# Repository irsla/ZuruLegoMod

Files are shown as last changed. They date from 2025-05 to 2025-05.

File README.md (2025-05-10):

# ZuruLegoMod
Hardware Mod for the Zuru Max Retro Computer Lego

This project was created for a friend (@CabriDIY) , it hasn't been curated and will most certainly not get any update.













## Building the firmware

The source code should build with any arm-none-eabi- GCC compilers.

```console
$ make
[...]
arm-none-eabi-size build/firmware_LegoZuru.elf
   text	   data	    bss	    dec	    hex	filename
 737740	    200	 191496	 929436	  e2e9c	build/firmware_LegoZuru.elf
arm-none-eabi-objcopy -O ihex build/firmware_LegoZuru.elf build/firmware_LegoZuru.hex
arm-none-eabi-objcopy -O binary -S build/firmware_LegoZuru.elf build/firmware_LegoZuru.bin
```

## Hardware

**The hardware was generated on KiCad**
  - schematics (pdf)
  - gerbers
  - BOMs
  - positions
  - 3D stl
  - Tutorial - photo only (PDF)

Project was manufactured and assembled by JLCPCB
 
**Not Included in the documentation:**
 - OLED Display: NHD-1.8-160128B, datasheet in folder Hardware
 - FPV ribbon: 10pin 0.5mm pitch type A (careful **not** to use a type B)
 - Power: any 5V, we used a 5V only usb cable

## Some photos

### 211 lego pieces:



### very first try of a GIF (I think the color was not correctly parsed)



### Oh No I have a dead pixel



### first main board was incorrect (I had to bodge)

signal-2025-04-14-19-46-56-328

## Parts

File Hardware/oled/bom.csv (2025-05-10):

Designator | Footprint | Quantity | Value | LCSC Part #
C17 | C_0402 | 1 | 4.7uF 50V
C18 | C_0402 | 1 | 4.7uF
C19 | C_0402 | 1 | 0.1uF
C20, C21, C22 | C_0402 | 3 | 1uF
D3, D4 | RB500VM-40TE-17 | 2 | RB500VM
J1 | HC-FPC-05-LT-10RLTAG | 1 | HC-FPC-05-LT-10RLTAG
J2 | F-FPC0N34P-D311 | 1 | ~
R1 | R_0402 | 1 | 49.9
R3 | R_0402 | 1 | 1.2M

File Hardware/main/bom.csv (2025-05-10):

Designator | Footprint | Quantity | Value | LCSC Part #
C1, C2 | C_0402 | 2 | 15pF
C10, C27 | C_0402 | 2 | 4.7uF
C11, C12, C16, C24, C28, C5, C6, C7, C8, C9 | C_0402 | 10 | 100nF
C13, C14 | C_0402 | 2 | 2.2uF
C15 | C_0402 | 1 | 1uF
C23, C25 | C_0805 | 2 | 22uF
C26 | C_0402 | 1 | 10uF
C3, C4 | C_0402 | 2 | 5.6pF
D1 | TJ-S4008SW4TGLCCW-A5 | 1 | ~
D2 | RB500VM-40TE-17 | 1 | RB500VM
J4 | J_SWD | 1 | ~
J5 | Header_1x02_2.54_TH_labels | 1 | ~
J6 | HC-FPC-05-LT-10RLTAG | 1 | HC-FPC-05-LT-10RLTAG
L1 | L_0603 | 1 | 4.7uH
R10, R11, R12, R7, R8, R9 | R_0402 | 6 | 47K
R13 | R_0402 | 1 | 200
R2 | R_0402 | 1 | 100K
R4 | R_0402 | 1 | 220K 1%
R5 | R_0402 | 1 | 18K 1%
R6 | R_0402 | 1 | 270K 1%
U1 | STM32H563VIT6 | 1 | ~
U2 | EA2208 | 1 | EA2208T6R
U3 | TPS7B6933 | 1 | TPS7B6933DBVR
U4 | Molex_uSD_Card_503398-1892 | 1 | MOLEX-SDCARD-503398-1892
Y2 | NX2016SA-25MHZ-STD-CZS-2 | 1 | NX2016SA-25MHZ-STD-CZS-2
Y3 | ABS25-32.768KHz | 1 | 32.768KHZ

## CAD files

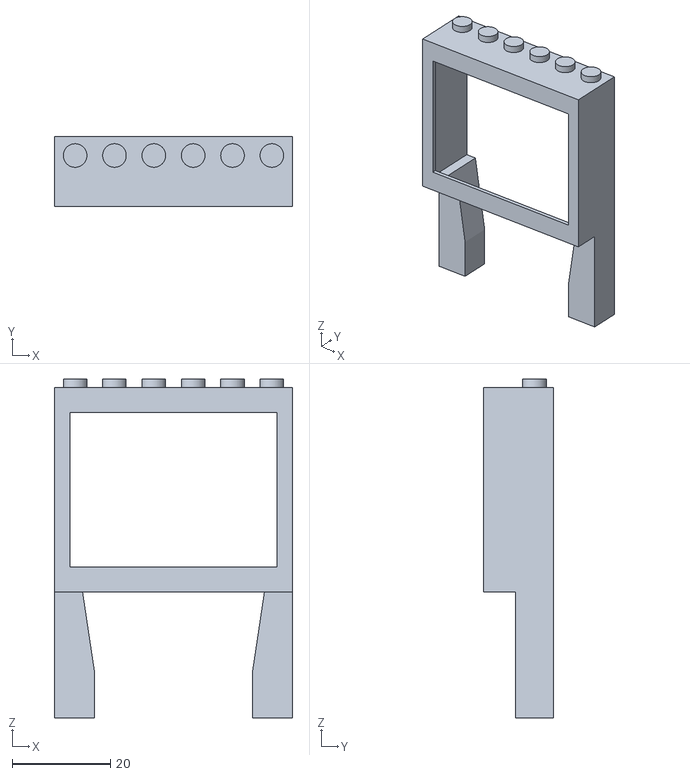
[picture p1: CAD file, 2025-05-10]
Hardware/DisplayHolder/display_case.stl
48.4 x 14.3 x 68.9

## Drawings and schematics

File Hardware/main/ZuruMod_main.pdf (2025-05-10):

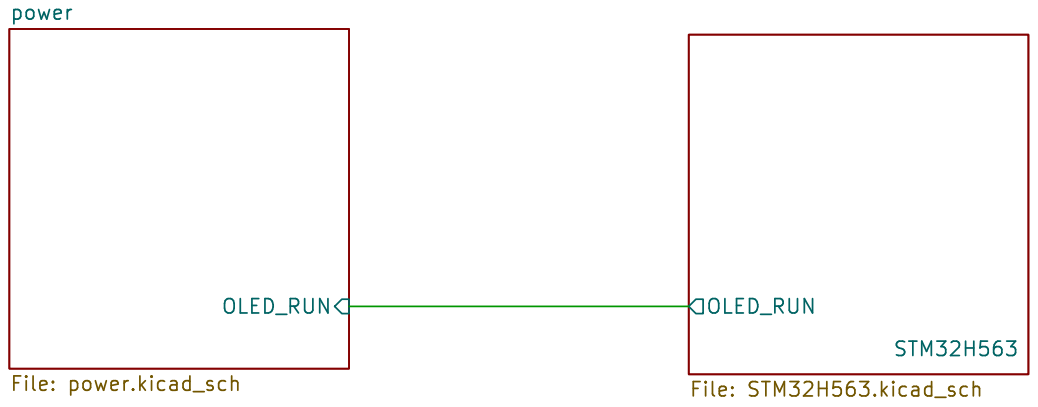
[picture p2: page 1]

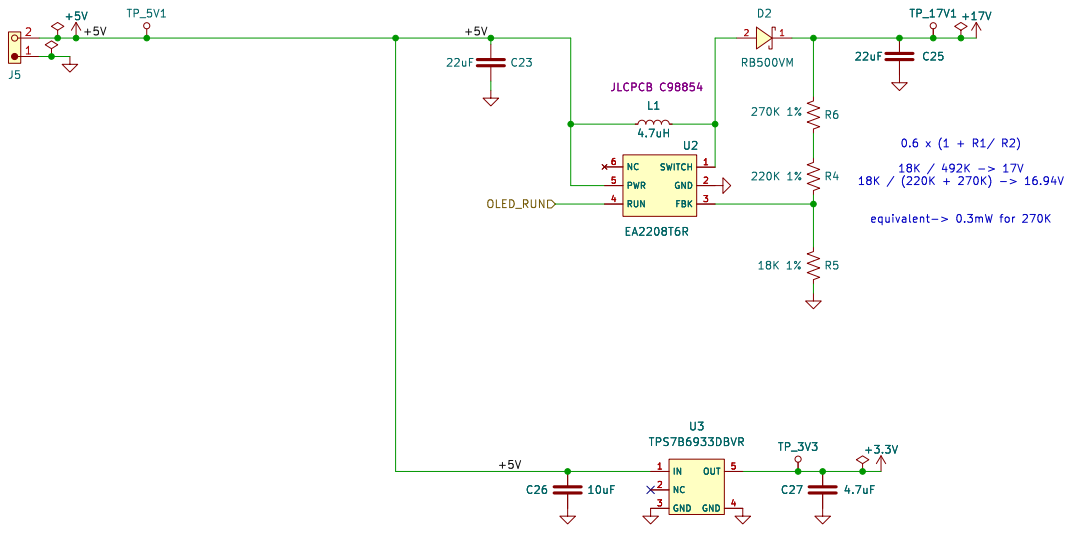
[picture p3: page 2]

Irsla
File: power.kicad_sch Sheet: /power/
Id: 2/3 Title: ZuruLegoMod

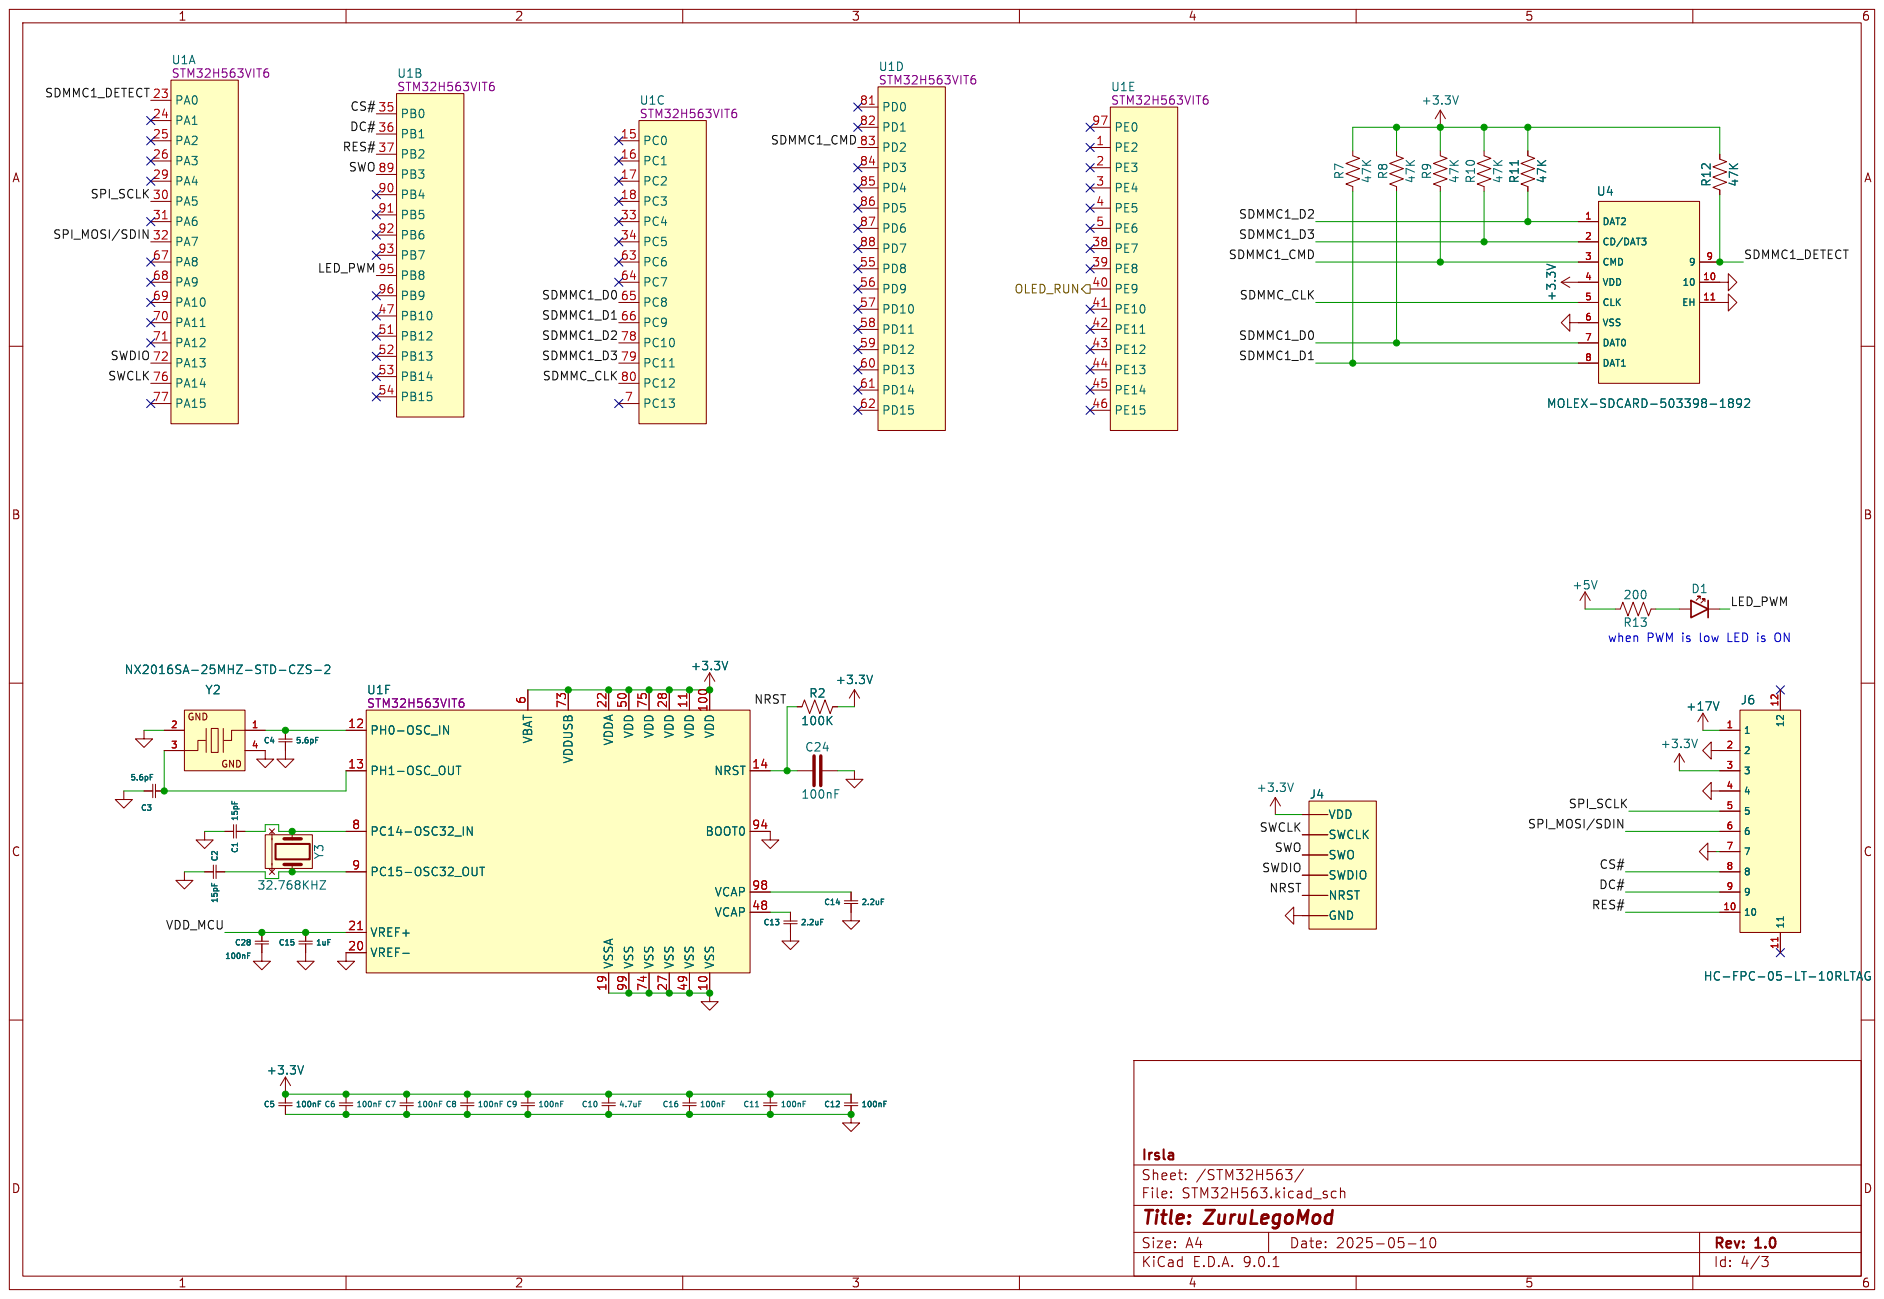
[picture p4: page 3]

6 VDDUSB 73 VDDA 22 VSSA 19 VDD 50 VSS 99 VDD 75 VSS 74 VDD 28 VSS 27 VDD 11 VSS 49 VDD100 VSS 10 NRST 14 BOOT0 94 VCAP 98 VCAP 48 U1F STM32H563VIT6 Y3

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

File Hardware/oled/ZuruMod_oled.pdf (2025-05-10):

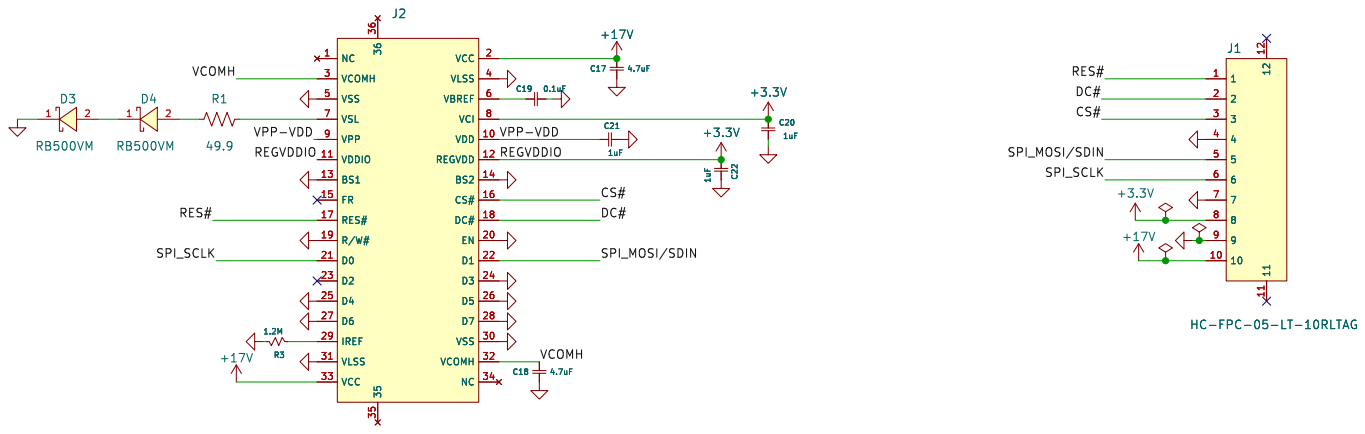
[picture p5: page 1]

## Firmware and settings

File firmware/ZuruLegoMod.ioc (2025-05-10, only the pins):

Mcu.UserName=STM32H563VITx
PA0.GPIO_Label=SDMMC1_DETECT
PA0.Signal=GPXTI0
PA13(JTMS/SWDIO).Signal=DEBUG_JTMS-SWDIO
PA14(JTCK/SWCLK).Signal=DEBUG_JTCK-SWCLK
PA5.Signal=SPI1_SCK
PA6.Signal=SPI1_MISO
PA7.Signal=SPI1_MOSI
PB0.GPIO_Label=SCREEN_CS
PB0.Signal=GPIO_Output
PB1.GPIO_Label=SCREEN_DC
PB1.Signal=GPIO_Output
PB2.GPIO_Label=SCREEN_RES
PB2.Signal=GPIO_Output
PB3(JTDO/TRACESWO).Signal=DEBUG_JTDO-SWO
PB8.GPIO_Label=LED_PWM
PB8.Signal=GPIO_Output
PC10.Signal=SDMMC1_D2
PC11.Signal=SDMMC1_D3
PC12.Signal=SDMMC1_CK
PC14-OSC32_IN(OSC32_IN).Signal=RCC_OSC32_IN
PC15-OSC32_OUT(OSC32_OUT).Signal=RCC_OSC32_OUT
PC8.Signal=SDMMC1_D0
PC9.Signal=SDMMC1_D1
PD2.Signal=SDMMC1_CMD
PE9.GPIO_Label=OLED_EN
PE9.Signal=GPIO_Output
PH0-OSC_IN(PH0).Signal=RCC_OSC_IN
PH1-OSC_OUT(PH1).Signal=RCC_OSC_OUT

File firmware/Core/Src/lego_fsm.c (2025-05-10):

#include "main.h"
#include "lego_fsm.h"
#include "nhd_1_8_160128B.h"
#include "app_filex.h"

static lego_fsm_t lego = {0};
ALIGN_32BYTES(uint32_t fsm_media_memory[64 * FX_STM32_SD_DEFAULT_SECTOR_SIZE / sizeof(uint32_t)]);

extern const unsigned int all_brand_gif_len;
extern const unsigned char const all_brand_gif[];

void init_lego_fsm(void) {
  lego.state = LEGO_FSM_INIT;
  lego.flags = 0x00;
  lego.sd_card = GPIO_PIN_SET;
  lego.sdio_disk = NULL;
  memset(lego.filename, 0, FX_MAX_LONG_NAME_LEN);

  nhd_160128b_init();
  nhd_160128b_FillScreen(0x0000);
  return;
}

void destroy_lego_fsm(void) {
  return;
}

static uint32_t file_read_pos = 0;

unsigned int lego_memory_read(void *handler, uint8_t* buf, uint32_t buf_size, unsigned long *real_size) {
  memcpy(buf, &all_brand_gif[file_read_pos], buf_size);
  file_read_pos += buf_size;
  *real_size = buf_size;
  return FX_SUCCESS;
}

void lego_store_scanline(unsigned char *line, int line_len, int line_num) {
  uint32_t offset = (160 - (line_len / 3)) / 2;
  for (int i = 0; i < 160; i++) {
    if (i < (line_len / 3)) {
      int r = line[i * 3];
      int g = line[i * 3 + 1];
      int b = line[i * 3 + 2];
      uint16_t rgb = ((r & 0b11111000) << 8) | ((g & 0b11111100) << 3) | (b >> 3);
      asm("REV16 %0,%1" : "=r"(rgb) : "r"(rgb));
      lego.display_buffer[160 * (128 - line_num) + i + offset] = rgb;
    }
  }
}

void lego_fsm(void) {
  UINT status;
  GPIO_PinState cur = HAL_GPIO_ReadPin(SDMMC1_DETECT_GPIO_Port, SDMMC1_DETECT_Pin);
  // put it on the stack

  if (cur != lego.sd_card) {
    lego.sd_card = cur;
    switch(cur) {
    case GPIO_PIN_RESET:
      // card inserted
      lego.state = LEGO_FSM_INIT_SD;
      break;
    case GPIO_PIN_SET:
      // card removed
      lego.state = LEGO_FSM_CLEAN;
      break;
    }
    HAL_Delay(20);
  }

  switch (lego.state) {
    case LEGO_FSM_INIT:
      lego.state = LEGO_FSM_IDLE;
      break;
    case LEGO_FSM_INIT_SD:
      if ((lego.flags & LEGO_SD_INIT) == 0x00) {
	MX_SDMMC1_SD_Init();
	lego.flags |= LEGO_SD_INIT;
      }
      if (lego.sdio_disk == NULL) {
	lego.sdio_disk = calloc(1, sizeof(FX_MEDIA));
	if (lego.sdio_disk == NULL) {
	  lego.state = LEGO_FSM_CLEAN;
	  return;
	}
      }
      if ((lego.flags & LEGO_MEDIA_OPEN) == 0x00) {
	status =  fx_media_open(lego.sdio_disk, "STM32_SDIO_DISK",
				fx_stm32_sd_driver, 0,
				(VOID *) fsm_media_memory, sizeof(fsm_media_memory));
	if (status != FX_SUCCESS) {
	  lego.state = LEGO_FSM_CLEAN;
	} else {
	  lego.flags |= LEGO_MEDIA_OPEN;
	  lego.state = LEGO_FSM_GET_NEXTFILE;
	}
      }
      break;
    case LEGO_FSM_GET_NEXTFILE:
      status = fx_directory_next_entry_find(lego.sdio_disk, lego.filename);
      if (status == FX_NO_MORE_ENTRIES) {
	status = fx_directory_first_entry_find(lego.sdio_disk, lego.filename);
      }
      if (status != FX_SUCCESS) {
	lego.state = LEGO_FSM_CLEAN;
      } else {
#define JPG	".jpg"
#define GIF	".gif"
	if (strcmp(&lego.filename[strlen(lego.filename) - strlen(JPG)], JPG) == 0) {
	  lego.state = LEGO_FSM_OPEN_JPG;
	} else 	if (strcmp(&lego.filename[strlen(lego.filename) - strlen(GIF)], GIF) == 0) {
	  lego.state = LEGO_FSM_OPEN_GIF;
	} else {
	  lego.state = LEGO_FSM_GET_NEXTFILE;
	}
      }
      break;
    case LEGO_FSM_OPEN_JPG:
      if (lego.fx_file == NULL) {
	lego.fx_file = calloc(1, sizeof(FX_FILE));
	if (lego.fx_file == NULL) {
	  lego.state = LEGO_FSM_CLEAN;
	  return;
	}
      }
      status = fx_file_open(lego.sdio_disk,
			    lego.fx_file,
			    lego.filename,
			    FX_OPEN_FOR_READ);
      if (status != FX_SUCCESS) {
	lego.state = LEGO_FSM_CLEAN;
      } else {
	lego.state = LEGO_FSM_READ_JPG;
      }
      break;
    case LEGO_FSM_READ_JPG:
      memset(lego.display_buffer, 0x00, sizeof(lego.display_buffer));
      status = fx_file_read(lego.fx_file, lego.file_data, sizeof(lego.file_data), &lego.file_size);
      if (status != FX_SUCCESS) {
	lego.state = LEGO_FSM_CLEAN;
      } else {
	struct jpeg_error_mgr jerr;
	struct jpeg_decompress_struct cinfo;
	JSAMPARRAY buffer;		/* Output row buffer */
	int row_stride;

	cinfo.err = jpeg_std_error(&jerr);
	jpeg_create_decompress(&cinfo);
	jpeg_mem_src(&cinfo, lego.file_data, lego.file_size);
	(void) jpeg_read_header(&cinfo, TRUE);
	jpeg_start_decompress(&cinfo);

	row_stride = cinfo.output_width * cinfo.output_components;
	buffer = (*cinfo.mem->alloc_sarray)
	  ((j_common_ptr) &cinfo, JPOOL_IMAGE, row_stride, 1);
	while (cinfo.output_scanline < cinfo.output_height) {
	  (void) jpeg_read_scanlines(&cinfo, buffer, 1);
	  lego_store_scanline(buffer[0], row_stride, cinfo.output_scanline);
	}
	cinfo.mem->free_pool((j_common_ptr) &cinfo, JPOOL_IMAGE);

	jpeg_finish_decompress(&cinfo);

	jpeg_destroy_decompress(&cinfo);

	lego.display_width = 160;
	lego.display_height = 128;
	lego.next = LEGO_FSM_JPG_WAIT;
	lego.state = LEGO_FSM_DISPLAY;
      }
      break;
    case LEGO_FSM_JPG_WAIT:
      {
	static uint32_t jpg_wait_until = 0;
	uint32_t cur = HAL_GetTick();

	if (jpg_wait_until == 0) {
	  jpg_wait_until = cur + 2000;
	}
	if (cur > jpg_wait_until) {
	  lego.state = LEGO_FSM_CLOSE_FILE;
	  jpg_wait_until = 0;
	}
      }
    break;
    case LEGO_FSM_OPEN_GIF:
      if (lego.fx_file == NULL) {
	lego.fx_file = calloc(1, sizeof(FX_FILE));
	if (lego.fx_file == NULL) {
	  lego.state = LEGO_FSM_CLEAN;
	  return;
	}
      }
      status = fx_file_open(lego.sdio_disk,
			    lego.fx_file,
			    lego.filename,
			    FX_OPEN_FOR_READ);
      if (status != FX_SUCCESS) {
	lego.state = LEGO_FSM_CLEAN;
      } else {
	lego.state = LEGO_FSM_READ_GIF_HDR;
      }
      break;
    case LEGO_FSM_READ_GIF_HDR:
      memset(lego.display_buffer, 0, sizeof(lego.display_buffer));
      lego.gif = gif_init(lego.fx_file, fx_file_read);
      gif_get_hdr(lego.gif);
      lego.state = LEGO_FSM_GET_GIF_IMG;
      break;
    case LEGO_FSM_GET_GIF_IMG:
      {
	int res;
	gif_frame_t frame = {0};

	frame.output = lego.display_buffer;
	frame.bit_pos = 0;

	res = gif_get_img(lego.gif, &frame);
	if (res == 0) {
	  lego.display_delay = (frame.gce.delay * 10);
	  lego.display_width = lego.gif->width;
	  lego.display_height = lego.gif->height;
	  lego.next = LEGO_FSM_GET_GIF_IMG;
	  if (lego.display_delay >= 50) {
	    lego.next = LEGO_FSM_GIF_WAIT;
	  }
	  lego.state = LEGO_FSM_DISPLAY;
	} else {
	  lego.state = LEGO_FSM_CLOSE_FILE;
	}
      }
      break;
    case LEGO_FSM_GIF_WAIT:
      {
	static uint32_t	gif_wait_until = 0;
	uint32_t cur = HAL_GetTick();
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

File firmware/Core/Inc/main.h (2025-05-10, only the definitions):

#define SDMMC1_DETECT_Pin GPIO_PIN_0
#define SDMMC1_DETECT_GPIO_Port GPIOA
#define SDMMC1_DETECT_EXTI_IRQn EXTI0_IRQn
#define SCREEN_CS_Pin GPIO_PIN_0
#define SCREEN_CS_GPIO_Port GPIOB
#define SCREEN_DC_Pin GPIO_PIN_1
#define SCREEN_DC_GPIO_Port GPIOB
#define SCREEN_RES_Pin GPIO_PIN_2
#define SCREEN_RES_GPIO_Port GPIOB
#define OLED_EN_Pin GPIO_PIN_9
#define OLED_EN_GPIO_Port GPIOE
#define LED_PWM_Pin GPIO_PIN_8
#define LED_PWM_GPIO_Port GPIOB

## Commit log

2025-05-10 import firmware AS-IS
    [st_config.cfg]
2025-05-10 add Hardware information
    [bom.csv, display_case.stl, positions.csv]

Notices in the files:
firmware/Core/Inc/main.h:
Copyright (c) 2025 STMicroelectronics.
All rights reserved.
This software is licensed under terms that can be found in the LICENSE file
